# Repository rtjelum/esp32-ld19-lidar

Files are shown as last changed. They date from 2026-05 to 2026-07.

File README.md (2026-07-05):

# ESP32 LD19 LiDAR Project

This project implements a portable LiDAR scanner and visualization tool using a **LilyGo T-Display-S3** (ESP32-S3 with AMOLED display) and an **LD19 LiDAR** sensor.

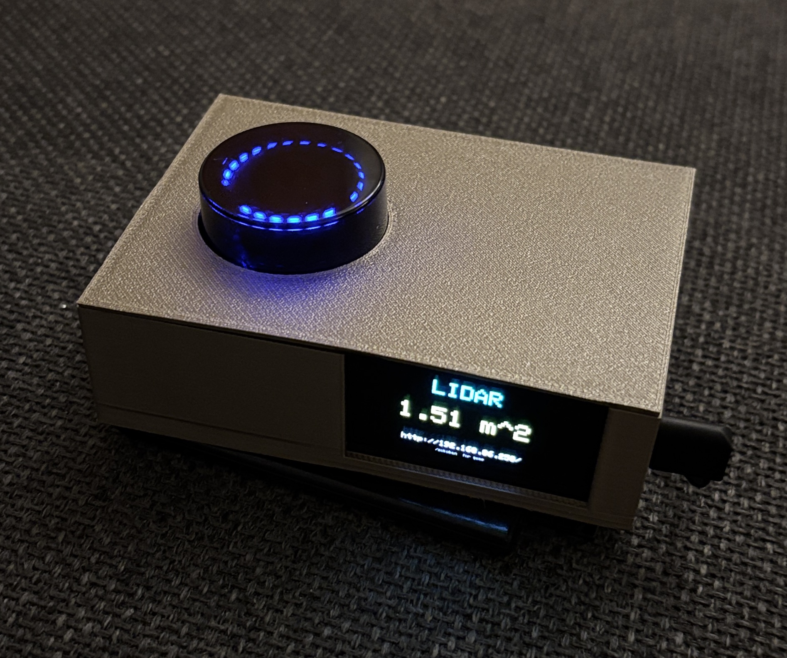
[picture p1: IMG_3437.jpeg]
Project Overview


*The assembled LiDAR scanner in its custom enclosure.*

## Features

- **Real-time Visualization:** Displays live LiDAR point cloud data on the 536x240 AMOLED screen.
- **Touch UI:** On-screen buttons (CST816 capacitive touch) to toggle person tracking, an area-only view, the IMU readout, and recording.
- **IMU:** Optional BMI160 (accel + gyro) for motion deskew; shown live on screen and logged with the LiDAR.
- **On-device Recording:** Logs synchronized LiDAR + IMU to the onboard flash as `.ldim`, downloadable over WiFi.
- **Host Toolchain:** Pull recordings and turn them into floorplans, MCAP, or an interactive 3-D view (`tools/`).
- **Web Interface:** Includes a built-in web server to monitor data and configure the device over WiFi.
- **Custom Enclosure:** A two-piece 3D-printable snap-fit box designed specifically for these components.
- **Integrated Game:** Includes a built-in Sokoban game (reachable via the display/buttons).
- **Closed-loop Speed Control:** Holds the LiDAR at a default 10 Hz for consistent data acquisition.

## Hardware

- **MCU:** [LilyGo T-Display-S3 AMOLED](https://www.lilygo.cc/products/t-display-s3) (ESP32-S3, RM67162 536×240 AMOLED)
- **LiDAR:** LD19 LiDAR Sensor — RX on GPIO 44, speed PWM on GPIO 46
- **Touch:** CST816 capacitive controller (on-board, I²C bus 0 — SDA 3 / SCL 2, addr 0x15)
- **IMU (optional):** BMI160 accel + gyro on a second I²C bus (SDA 41 / SCL 39, addr 0x69), mounted with **+Y up**
- **Enclosure:** Custom 3D-printed case (see `build_box.py`)

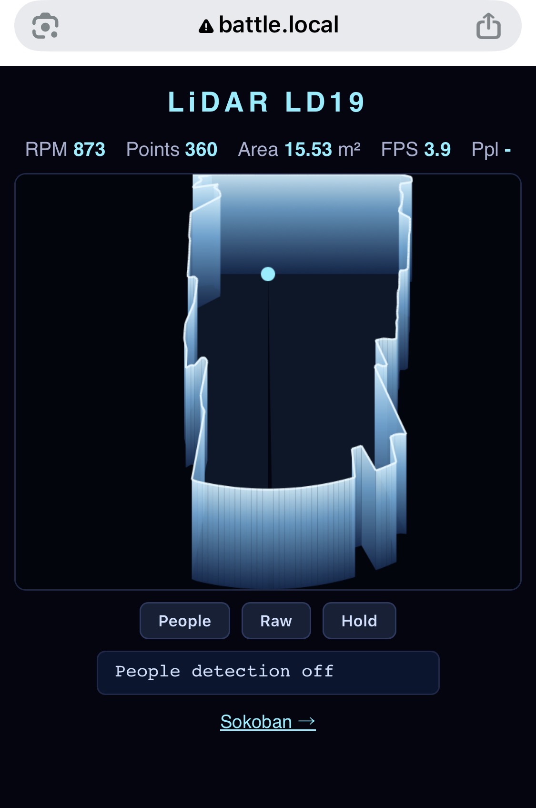
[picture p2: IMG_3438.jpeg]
Internal View


*Internal layout and component fitting.*

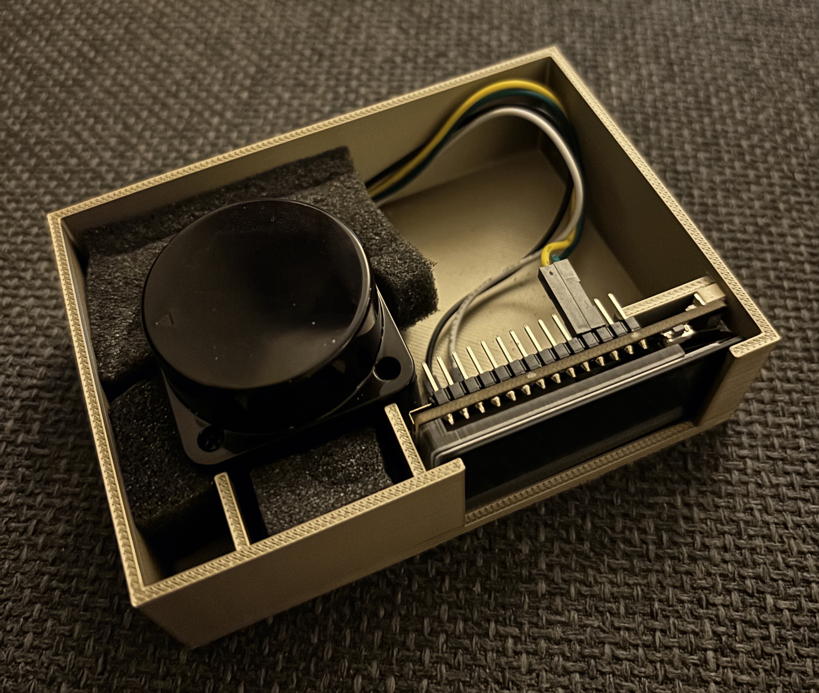
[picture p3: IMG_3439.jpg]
Component Placement


*LiDAR and T-Display seated in the bottom enclosure.*

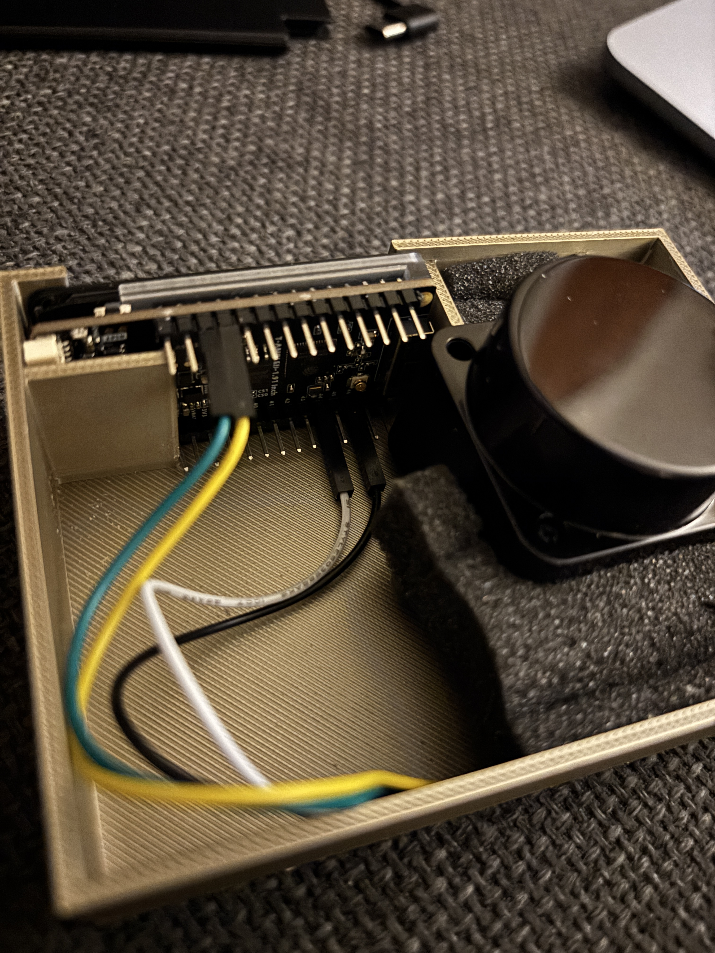
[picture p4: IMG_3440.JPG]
Wiring Detail


*Detail of the wiring connection between the MCU and the sensor.*

## Software Setup

### Firmware
The firmware is written in C++ for the Arduino framework. It uses the `Arduino_GFX` library for the AMOLED display.

**Build Requirements:**
- `arduino-cli`
- ESP32 Board Support (esp32:esp32:esp32s3)

To compile and flash:
```bash
make
```

### WiFi Setup

On first boot — or any boot with no stored credentials — the device starts a SoftAP captive setup:

1. Connect your phone or laptop to the WiFi network **`lidar-setup`** (open, no password).
2. Open **http://192.168.4.1/** in a browser. The setup page scans for nearby networks.
3. Tap an SSID to fill the field (or type it manually), enter the password, and press **Connect**.
4. The device stores the credentials in flash and reboots. The AMOLED then shows the station-mode URL (typically `http://lidar.local/` via mDNS).

To re-do setup later, open a serial console at 115200 baud and type one of:

- `clear` — wipes stored WiFi credentials and reboots into setup mode
- `reboot` — restart the device
- `help` — list commands

### Sokoban

The device serves a built-in Sokoban game at **http://lidar.local/sokoban** (or `/sokoban` on whichever IP is shown on the display).

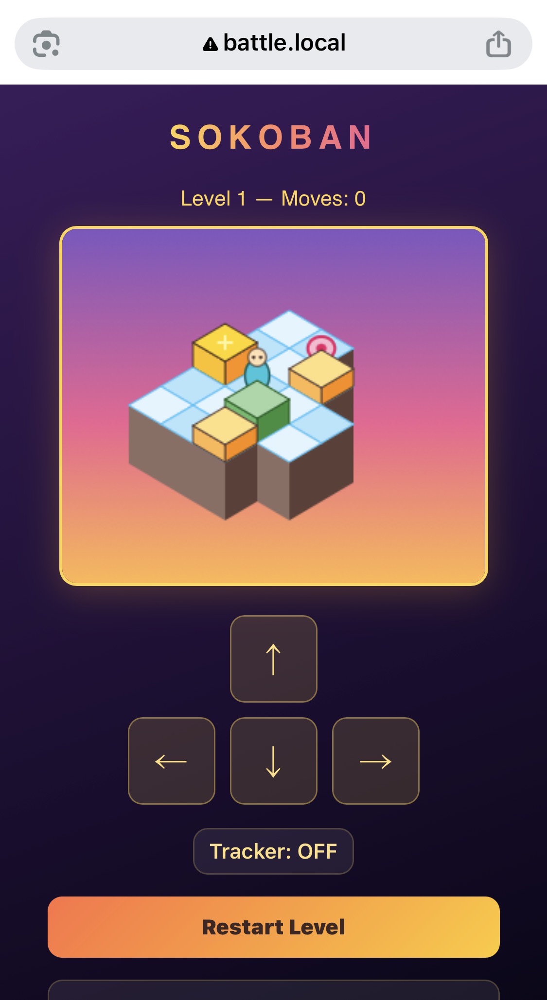
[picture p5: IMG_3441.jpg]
Sokoban running in a browser


*Sokoban running on the embedded web server, rendered isometrically.*

Push the green crates onto the pink goal pads. Each pad must hold one crate to clear the level — there are 50 levels in total, advancing automatically when the last crate is placed. Crates can only be pushed (never pulled) and only when the square behind them is empty, so plan ahead.

Two control modes:

- **D-pad / arrow keys** — tap the on-screen pad or use arrow keys on a desktop.
- **LiDAR motion control** — toggle **Tracker: ON** to stand in front of the sensor and step into one of the four direction cells in the 3×3 floor grid (the centre cell is "idle"). Each cell-entry fires one move; you have to step back to idle before re-entering the same cell.

### Touch Controls

The AMOLED's capacitive panel drives a four-button bar along the bottom of every screen:

- **TRACK** — toggle firmware person detection on/off (area measurement keeps running).
- **AREA** — full-screen scanned-area (m²) readout.
- **IMU** — live BMI160 readout (accel in g, gyro in dps, roll/pitch). Use it to align the mount: when upright the up axis reads ~+1.00 g and roll/pitch sit near 0.
- **REC** — start/stop recording. While recording the button turns red and shows the file size.

The LiDAR spins at a default **10 Hz** (closed-loop) from boot.

To sanity-check the touch panel in isolation, flash the standalone test sketch (it scans I²C and live-tracks touches), then re-flash the main firmware:

```bash
make touch-flash    # flash touch_test/
make flash          # restore the LiDAR firmware
```

### Recording & Floorplans

Recordings are written to the onboard FAT partition as `scan_NNN.ldim` (raw LD19 packets + mount-corrected IMU samples, the same format as the companion `rasp_pi_zero2_ld19_lidar` project). A host-side toolchain in `tools/` pulls them over WiFi and processes them.

```bash
make gui                      # desktop control panel wrapping every tool below
make pull-recordings          # download new .ldim from the device into recordings/
make list-recordings          # list what's on the device (no download)
make clear-device             # wipe all recordings on the device (skips the active one)
make clear-recordings         # delete local recordings + derived .mcap/.png
make floorplan                # deskew + point-to-line ICP + loop-closure floorplan PNG
make path                     # position-path PNG (SLAM trajectory over a faint map)
make viz                      # interactive PRBonn lidar-visualizer (auto-builds MCAP)
make mcap                     # just convert .ldim -> MCAP
make view                     # quick static matplotlib scatter
make dump                     # print a recording's duration + LD19/IMU counts
make help                     # list every make target
```

All processing targets default to the newest recording; override with `LDIM=recordings/scan_002.ldim`, and the device host with `HOST=lidar.local`. The Python venv (`tools/.venv`) is created automatically and **pins Python 3.13** (the visualizer / `rosbags` lack wheels for 3.14). `make viz` clones [PRBonn/lidar-visualizer](https://github.com/PRBonn/lidar-visualizer) on demand.

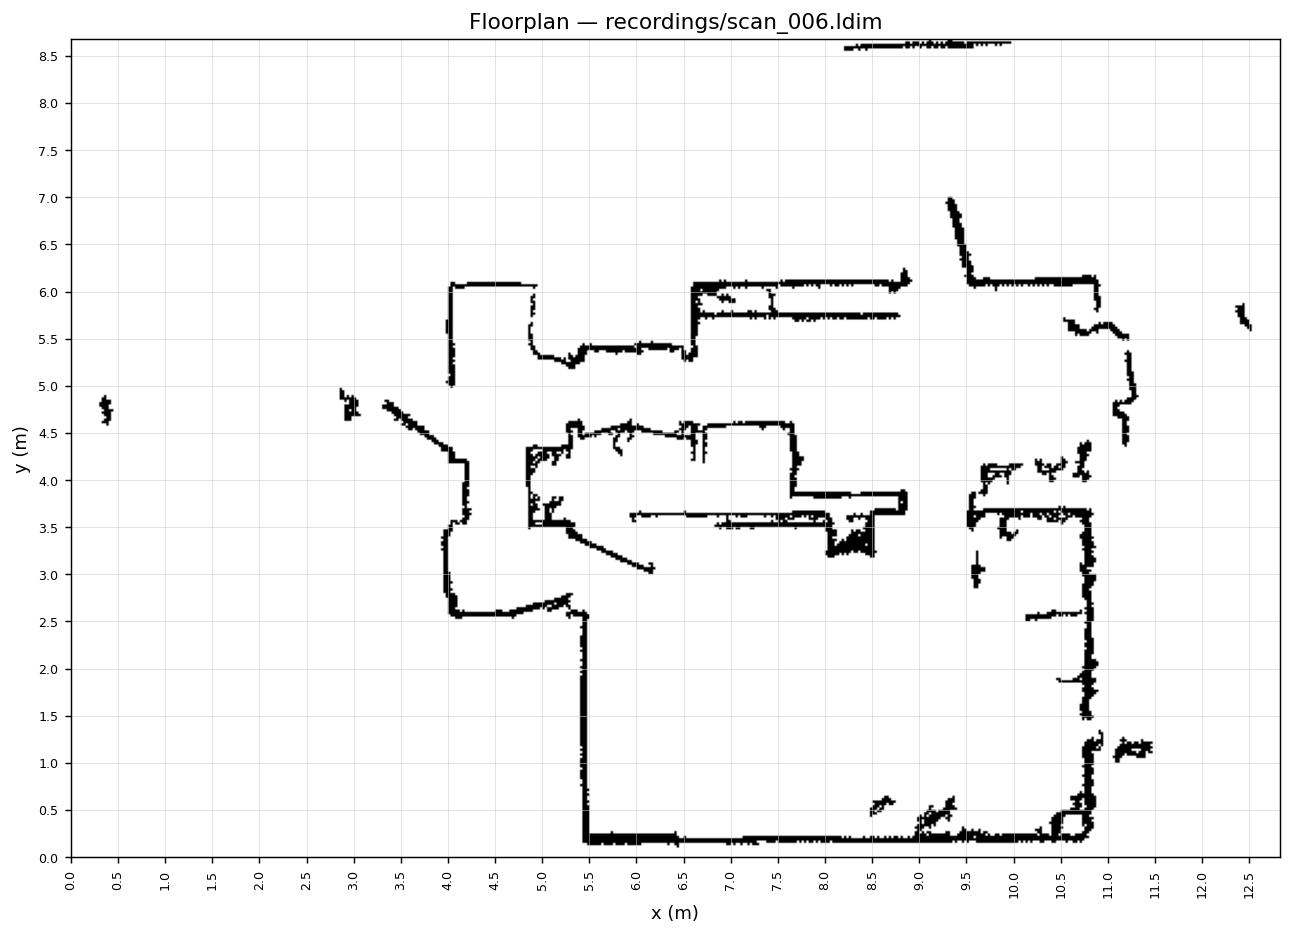
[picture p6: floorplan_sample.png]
Sample floorplan
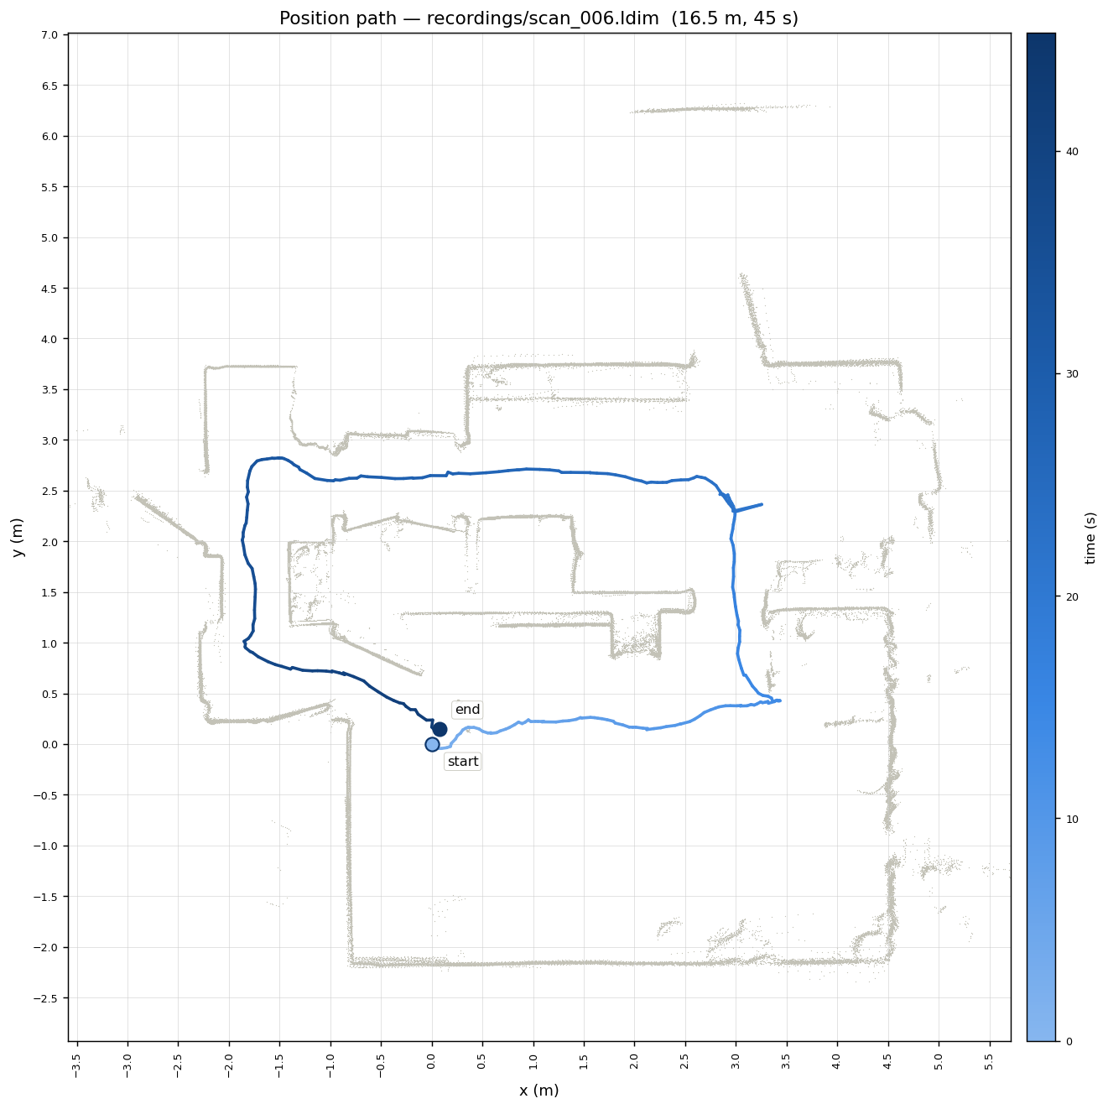
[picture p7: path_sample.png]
Sample position path
 

*From the same ~50 s handheld walk: the floorplan (`make floorplan` — gyro + translation deskew, point-to-line ICP, loop closure, global refinement) and the rig's position path over the same map (`make path` — light→dark blue with time).*

Recordings can also be managed over a 115200-baud serial console: `ls` (list), `rm <file>`, `i2c` (scan both buses for the touch/IMU controllers).

### Desktop GUI

```bash
make gui        # or: python3.13 lidar_gui.py
```

`lidar_gui.py` is a Tkinter control panel wrapping every make target above. It is stdlib-only but needs **Python 3.13** (the system `python3` ships without tkinter); the tools venv is built automatically the first time an action needs it.

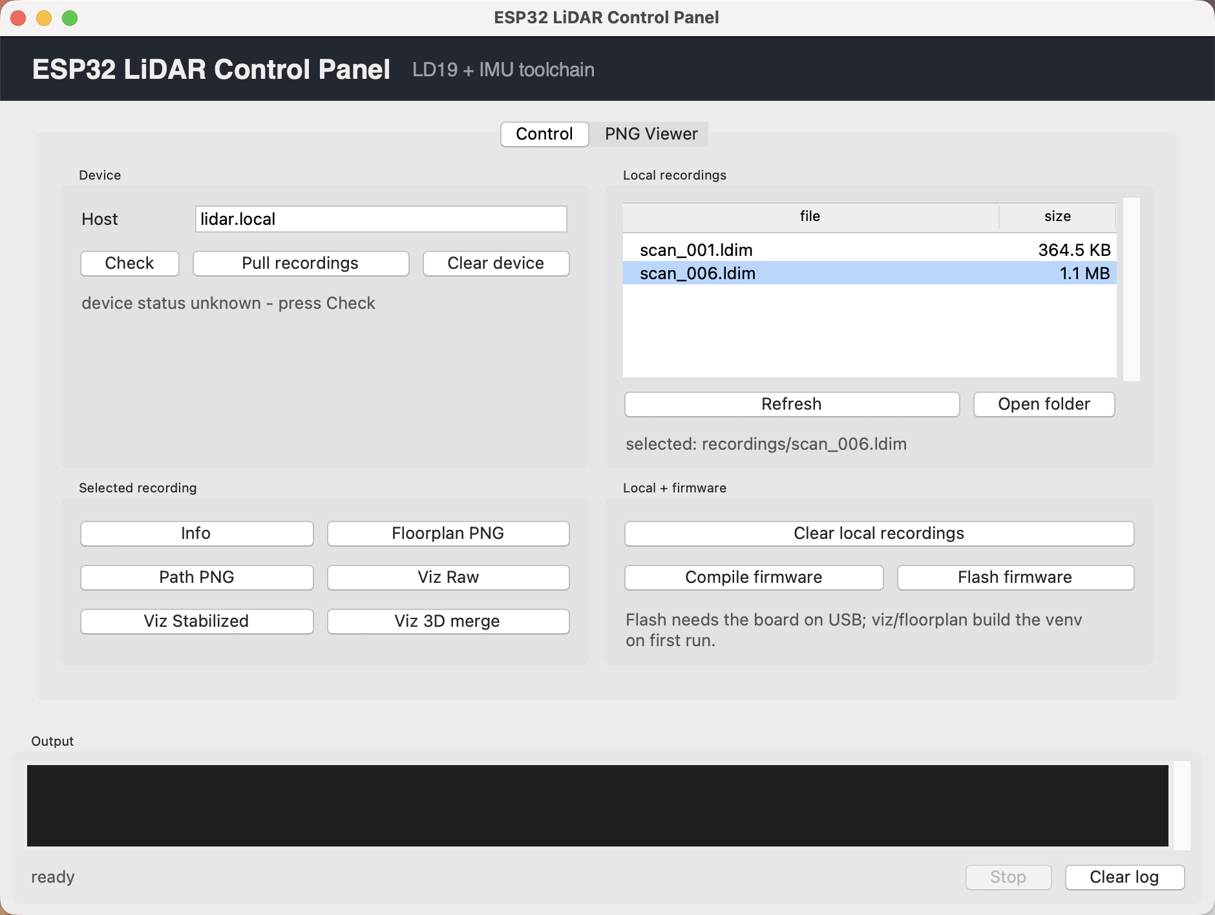
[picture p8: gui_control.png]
GUI Control tab


*The Control tab: device access, local recordings, per-recording actions, firmware, and the live output log.*

The window has two tabs plus a shared **Output** pane at the bottom that streams the live output of the running command — one command runs at a time, and **Stop** kills it.

**Control tab**

- **Device** — set the host (default `lidar.local`). **Check** shows the device's file count, free flash, and whether it is recording; **Pull recordings** downloads new `.ldim` files into `recordings/`; **Clear device** wipes the device (the file currently being recorded is skipped).
- **Local recordings** — lists `recordings/*.ldim` with the newest pre-selected; **Refresh** rescans, **Open folder** opens it in Finder.
- **Selected recording** — runs a tool on the highlighted file:
  - **Info** — duration + LD19/IMU sample counts (`make dump`)
  - **Floorplan PNG** — SLAM floorplan (`make floorplan`)
  - **Path PNG** — the rig's position path over a faint point map (`make path`)
  - **Viz Raw / Viz Stabilized / Viz 3D merge** — the interactive 3-D viewers (`make viz` / `viz3d` / `viz3d-merge`)
- **Local + firmware** — delete local recordings and their derived files, compile the firmware, or flash it over USB.

**PNG Viewer tab** — browses the PNGs under `recordings/`, scaled to fit the window; **Open externally** hands the file to Preview. The two PNG-producing buttons (Floorplan, Path) switch to this tab automatically when they finish.

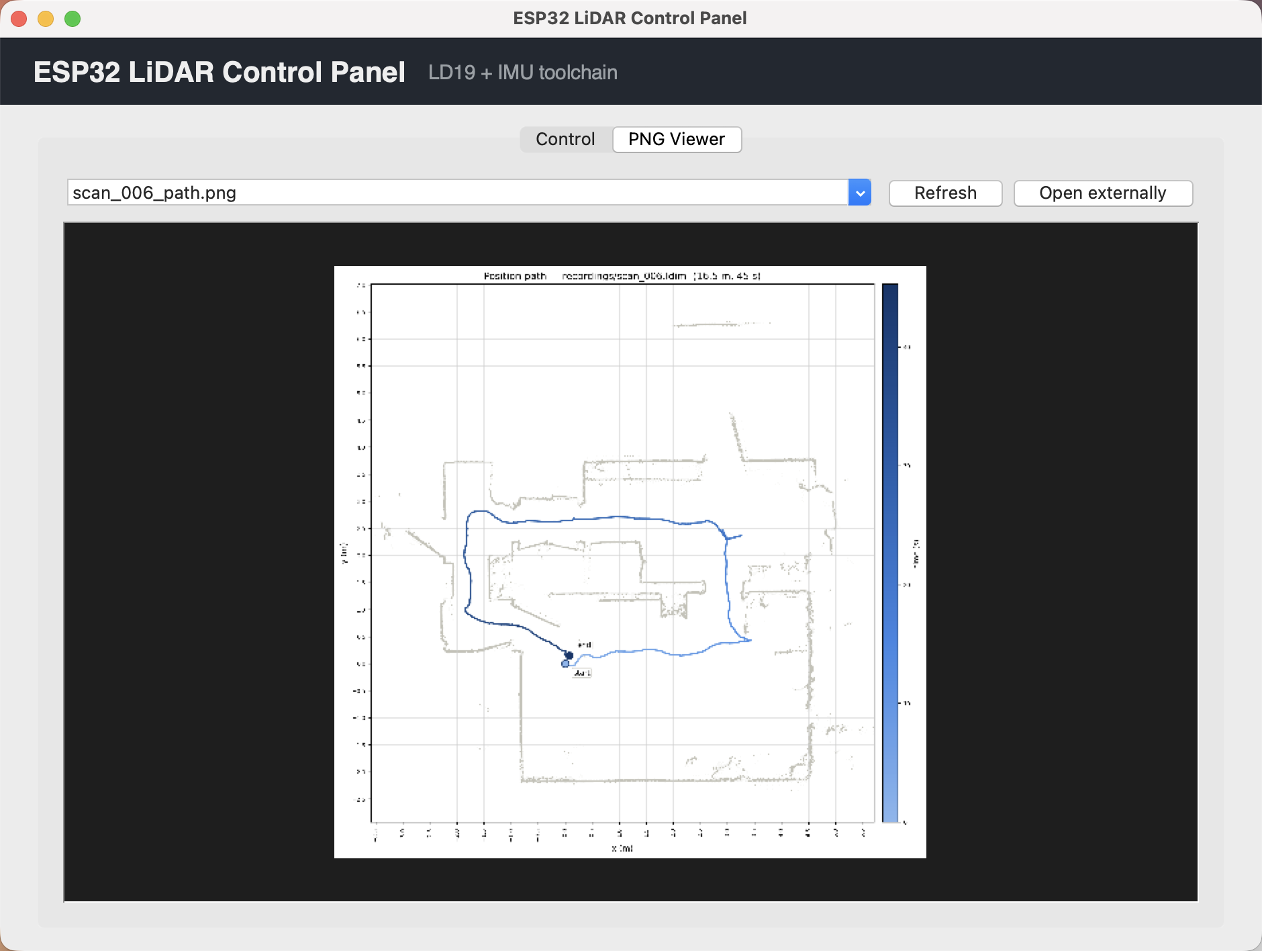
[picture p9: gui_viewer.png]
GUI PNG Viewer tab


*The PNG Viewer tab showing a position-path render.*

### Enclosure Design
The 3D-printable box is generated using a Python script that leverages geometric libraries.

**Requirements:**
- Python 3
- `numpy`
- `trimesh`
- `shapely`

To generate the STL files:
```bash
python3 build_box.py
```
This will produce `lidar_tdisplay_box_bottom.stl` and `lidar_tdisplay_box_top.stl`.

## File Structure

- `esp32-ld19-lidar.ino`: Main Arduino firmware.
- `lidar_page.h`, `sokoban_page.h`, `setup_page.h`, `sokoban_levels.h`, `localizer.h`: Web-page HTML, Sokoban data, and the localizer, included by the sketch.
- `touch_test/`: Standalone CST816 touch-panel test sketch (`make touch-flash`).
- `lidar_gui.py`: Tkinter desktop control panel for the host toolchain (`make gui`).
- `tools/`: Host `.ldim` toolchain — `pull_recordings.py`, `view_ldim.py`, `ldim_to_floorplan.py`, `ldim_to_mcap.py`, `ldim_to_3d_mcap.py`, `ldim_dump.py`.
- `build_box.py`: Python script to generate the 3D enclosure.
- `makefile`: Build system for the firmware and the host toolchain.
- `*.stl`: Generated 3D models for printing.
- `IMG_*.jpeg`: Project photos.

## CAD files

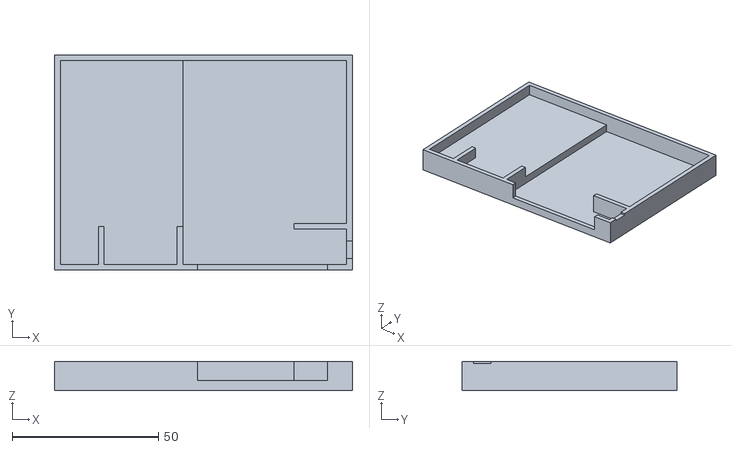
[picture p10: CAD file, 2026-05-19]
lidar_tdisplay_box_testfit.stl
102.0 x 73.7 x 10.0

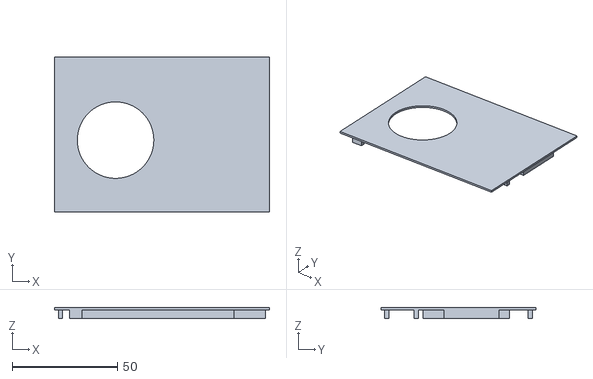
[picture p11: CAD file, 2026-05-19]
lidar_tdisplay_box_top.stl
102.0 x 73.7 x 5.00

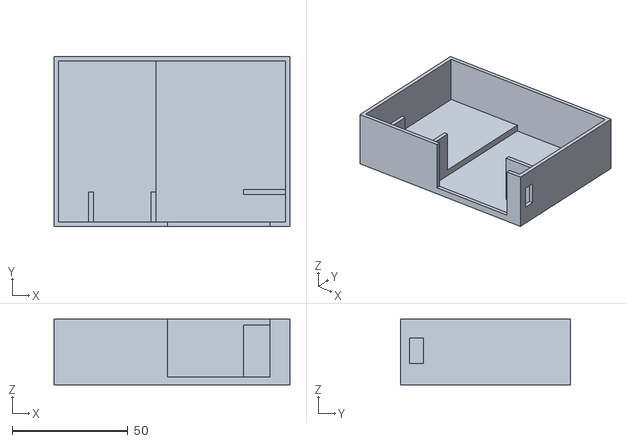
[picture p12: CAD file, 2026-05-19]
lidar_tdisplay_box_bottom.stl
102.0 x 73.7 x 28.5

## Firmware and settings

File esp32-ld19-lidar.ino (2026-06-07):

#include <WiFi.h>
#include <ESPmDNS.h>
#include <WebServer.h>
#include <Preferences.h>
#include <Arduino_GFX_Library.h>
#include <Wire.h>
#include <FFat.h>
#include <esp_timer.h>
#include "lidar_page.h"
#include "sokoban_page.h"
#include "sokoban_levels.h"
#include "setup_page.h"
#include "localizer.h"

// ── AMOLED (RM67162, 536×240 physical) ──────────────────────────────────────
#define LCD_CS   6
#define LCD_SCLK 47
#define LCD_D0   18
#define LCD_D1   7
#define LCD_D2   48
#define LCD_D3   5
#define LCD_RST  17
#define LCD_PWR  15

#define BLACK  0x0000
#define WHITE  0xFFFF
#define GREEN  0x0500
#define BLUE   0x0016

// ── Touch (CST816 capacitive, I2C) ──────────────────────────────────────────
#define TOUCH_SDA  3
#define TOUCH_SCL  2
#define TOUCH_INT  21
#define TOUCH_ADDR 0x15
struct TouchPt { bool pressed; uint16_t x, y; };

// ── IMU on a second I2C bus (Wire1) ─────────────────────────────────────────
#define IMU_SDA  41
#define IMU_SCL  39

Arduino_DataBus *bus = nullptr;
Arduino_GFX     *gfx_dev = nullptr;
Arduino_Canvas  *gfx = nullptr; // off-screen PSRAM framebuffer; flush() pushes to gfx_dev

static const int DISP_W = 536;
static const int DISP_H = 240;

Preferences prefs;
char ssid[64]     = "";
char password[64] = "";

constexpr uint32_t fnv1a(const char* s, uint32_t h = 2166136261u) {
    return *s ? fnv1a(s + 1, (h ^ (uint8_t)*s) * 16777619u) : h;
}
constexpr uint32_t BUILD_HASH = fnv1a(__DATE__ " " __TIME__);

static bool          apMode = false;
static unsigned long skLastSeen = 0;
WebServer server(80);

// ── LiDAR LD19 ────────────────────────────────────────────────────────────────
#define LIDAR_RX_PIN  44
#define LIDAR_PWM_PIN 46
#define LIDAR_PWM_FREQ 1000   // LD19P external speed control: 500 Hz – 1.5 kHz
#define LIDAR_PWM_RES  8
#define LIDAR_BAUD   230400
#define LIDAR_PKT_LEN 47
#define LIDAR_POINTS_PER_PKT 12
// Returns are clamped to the LD19's rated maximum range. The sensor does not
// report valid hits beyond this, so it acts as a safety ceiling rather than an
// artificial limit. Front and rear are treated symmetrically to avoid the
// rendering discontinuity at the 90°/270° boundary.
#define LIDAR_MAX_RANGE_MM 12000
static const int LIDAR_BUF_POINTS = 480; // ~40 packets, ≈ 1 full rotation @10Hz
static volatile uint8_t  lidarPwmDuty   = 128;   // 50% — also LD19 external-mode entry duty
static volatile bool     lidarMotorOn   = true;
static volatile uint32_t lidarPwmFreq   = LIDAR_PWM_FREQ;
static volatile bool     lidarPwmInvert = false;
static volatile uint16_t lidarTargetRpm = 600;   // default 10 Hz closed-loop (0 = manual duty)
static inline void applyLidarPwm(){
  uint32_t d = lidarMotorOn ? lidarPwmDuty : 0;
  if (lidarPwmInvert) d = 255 - d;
  ledcWrite(LIDAR_PWM_PIN, d);
}

struct LidarPt { uint16_t angle_q2; uint16_t dist; uint8_t intensity; };
static LidarPt lidarBuf[LIDAR_BUF_POINTS];
static volatile uint16_t lidarHead = 0;
static volatile uint32_t lidarSeq  = 0;
static volatile uint16_t lidarSpeed = 0; // deg/sec
static portMUX_TYPE lidarMux = portMUX_INITIALIZER_UNLOCKED;

// ── Person detection state (posted back from browser via /people) ────────────
static portMUX_TYPE personMux = portMUX_INITIALIZER_UNLOCKED;
static volatile uint32_t personLastSeen = 0;
static volatile uint8_t  personCount = 0;
static const uint8_t PERSON_MAX = 6;
static float personAngle[PERSON_MAX]; // degrees, 0°=left, 90°=front, 180°=right
static float personDist[PERSON_MAX];  // meters
static float personX[PERSON_MAX];     // meters, +right
static float personY[PERSON_MAX];     // meters, +forward
static float bgDist[360];    // mm, per-bin rolling background for shadow detection
static volatile float lidarAreaM2 = 0.0f; // scanned polygon area in m²

// ── Touch UI state ───────────────────────────────────────────────────────────
static volatile bool personTrackingOn = true;  // TRACK button: gate personTask detection
static volatile bool bigAreaView      = false; // AREA button: full-screen m² readout
static volatile bool displayDirty     = false; // set by touchTask to force an immediate repaint
static volatile int  btnPressedIdx    = -1;    // which button is held (for press highlight)

// ── Recording state (REC button) ──────────────────────────────────────────────
// Writes raw LD19 packets to a .ldim file on the onboard 9 MB FAT partition, in
// the same format as ../rasp_pi_zero2_ld19_lidar (tools/ldim_*.py can read them).
// recWant is toggled by the touch task; all file I/O happens in lidarTask, which
// owns recFile, so no cross-task file locking is needed.
static volatile bool     recWant   = false;  // desired state (set by touch)
static volatile bool     recActive = false;  // actual state (set by lidarTask)
static volatile uint32_t recBytes  = 0;      // bytes written so far
static volatile int      recNo     = 0;      // current scan_NNN number
static File              recFile;
static int64_t           recStartUs = 0;
static SemaphoreHandle_t recMutex   = nullptr; // serializes recFile across lidar/imu tasks

// ── BMI160 IMU on Wire1 (addr 0x69) ────────────────────────────────────────────
#define BMI160_ADDR     0x69
#define BMI160_CHIPID   0xD1
static volatile bool  imuOk = false;
static volatile bool  imuView = false;                 // IMU button: live readout view
static volatile float imuAx = 0, imuAy = 0, imuAz = 0; // g, EMA-smoothed
static volatile float imuGx = 0, imuGy = 0, imuGz = 0; // dps, EMA-smoothed

// ── Localization state ──────────────────────────────────────────────────────
static portMUX_TYPE poseMux = portMUX_INITIALIZER_UNLOCKED;
static volatile float locX = 0.0f, locY = 0.0f, locTheta = 0.0f;
static volatile float locErr = 0.0f;
static volatile int   locInliers = 0;
static volatile bool  locValid = false;     // true once first ICP converges
static volatile bool  seedResetRequested = false;  // /lidar/map/reset sets this

static const uint8_t LD19_CRC_TABLE[256] = {
  0x00,0x4d,0x9a,0xd7,0x79,0x34,0xe3,0xae,0xf2,0xbf,0x68,0x25,0x8b,0xc6,0x11,0x5c,
  0xa9,0xe4,0x33,0x7e,0xd0,0x9d,0x4a,0x07,0x5b,0x16,0xc1,0x8c,0x22,0x6f,0xb8,0xf5,
  0x1f,0x52,0x85,0xc8,0x66,0x2b,0xfc,0xb1,0xed,0xa0,0x77,0x3a,0x94,0xd9,0x0e,0x43,
  0xb6,0xfb,0x2c,0x61,0xcf,0x82,0x55,0x18,0x44,0x09,0xde,0x93,0x3d,0x70,0xa7,0xea,
  0x3e,0x73,0xa4,0xe9,0x47,0x0a,0xdd,0x90,0xcc,0x81,0x56,0x1b,0xb5,0xf8,0x2f,0x62,
  0x97,0xda,0x0d,0x40,0xee,0xa3,0x74,0x39,0x65,0x28,0xff,0xb2,0x1c,0x51,0x86,0xcb,
  0x21,0x6c,0xbb,0xf6,0x58,0x15,0xc2,0x8f,0xd3,0x9e,0x49,0x04,0xaa,0xe7,0x30,0x7d,
  0x88,0xc5,0x12,0x5f,0xf1,0xbc,0x6b,0x26,0x7a,0x37,0xe0,0xad,0x03,0x4e,0x99,0xd4,
  0x7c,0x31,0xe6,0xab,0x05,0x48,0x9f,0xd2,0x8e,0xc3,0x14,0x59,0xf7,0xba,0x6d,0x20,
  0xd5,0x98,0x4f,0x02,0xac,0xe1,0x36,0x7b,0x27,0x6a,0xbd,0xf0,0x5e,0x13,0xc4,0x89,
  0x63,0x2e,0xf9,0xb4,0x1a,0x57,0x80,0xcd,0x91,0xdc,0x0b,0x46,0xe8,0xa5,0x72,0x3f,
  0xca,0x87,0x50,0x1d,0xb3,0xfe,0x29,0x64,0x38,0x75,0xa2,0xef,0x41,0x0c,0xdb,0x96,
  0x42,0x0f,0xd8,0x95,0x3b,0x76,0xa1,0xec,0xb0,0xfd,0x2a,0x67,0xc9,0x84,0x53,0x1e,
  0xeb,0xa6,0x71,0x3c,0x92,0xdf,0x08,0x45,0x19,0x54,0x83,0xce,0x60,0x2d,0xfa,0xb7,
  0x5d,0x10,0xc7,0x8a,0x24,0x69,0xbe,0xf3,0xaf,0xe2,0x35,0x78,0xd6,0x9b,0x4c,0x01,
  0xf4,0xb9,0x6e,0x23,0x8d,0xc0,0x17,0x5a,0x06,0x4b,0x9c,0xd1,0x7f,0x32,0xe5,0xa8
};

static uint8_t ld19Crc(const uint8_t* p, int n) {
  uint8_t c = 0;
  for (int i = 0; i < n; i++) c = LD19_CRC_TABLE[(c ^ p[i]) & 0xff];
  return c;
}

// ── Touch panel (CST816) + on-screen buttons ───────────────────────────────────
static bool touchRead(uint8_t reg, uint8_t *buf, uint8_t len) {
  Wire.beginTransmission(TOUCH_ADDR);
  Wire.write(reg);
  if (Wire.endTransmission(false) != 0) return false;
  if (Wire.requestFrom((int)TOUCH_ADDR, (int)len) != len) return false;
  for (uint8_t i = 0; i < len; i++) buf[i] = Wire.read();
  return true;
}

// One CST816 report: gesture, finger count, then X/Y hi/lo. The panel reports
// already in the landscape (536×240) frame, so x/y map straight to the canvas.
static TouchPt touchPoll() {
  TouchPt t = {false, 0, 0};
  uint8_t d[6];
  if (!touchRead(0x01, d, 6)) return t;
  uint8_t fingers = d[1];
  if (fingers == 0 || fingers > 2) return t;
  t.pressed = true;
  t.x = ((uint16_t)(d[2] & 0x0F) << 8) | d[3];
  t.y = ((uint16_t)(d[4] & 0x0F) << 8) | d[5];
  return t;
}

// Bottom button bar: four buttons across the 536-wide screen.
static const int BTN_N = 4;
static const int BTN_Y = 186, BTN_H = 48, BTN_W = 124;
static const int BTN_X[BTN_N] = {8, 140, 272, 404};

static int hitTestButton(int sx, int sy) {
  if (sy < BTN_Y || sy > BTN_Y + BTN_H) return -1;
  for (int i = 0; i < BTN_N; i++)
    if (sx >= BTN_X[i] && sx < BTN_X[i] + BTN_W) return i;
  return -1;
}

static void drawButton(int i, const char* label, bool active, uint16_t accent) {
  bool pressed = (btnPressedIdx == i);
  uint16_t fill = pressed ? 0x39C7 : (active ? ((accent >> 1) & 0x7BEF) : BLACK);
  uint16_t edge = active ? accent : 0x4a69;
  uint16_t txt  = active ? accent : WHITE;
  gfx->fillRoundRect(BTN_X[i], BTN_Y, BTN_W, BTN_H, 8, fill);
  gfx->drawRoundRect(BTN_X[i], BTN_Y, BTN_W, BTN_H, 8, edge);
  gfx->setTextSize(2);
  gfx->setTextColor(txt);
  int tw = (int)strlen(label) * 12;
  gfx->setCursor(BTN_X[i] + (BTN_W - tw) / 2, BTN_Y + (BTN_H - 16) / 2);
  gfx->print(label);
}

static void drawTouchButtons() {
  drawButton(0, personTrackingOn ? "TRACK ON" : "TRACK OFF", personTrackingOn, 0x07E0);
  drawButton(1, "AREA", bigAreaView, 0x07E0);
  drawButton(2, "IMU", imuView, 0x07E0);
  char rl[12];
  if (recActive) snprintf(rl, sizeof(rl), "REC %.1fM", recBytes / 1048576.0);
  else           strcpy(rl, "REC");
  drawButton(3, rl, recActive, 0xF800);  // red accent
}

// ── Recording (.ldim) — only ever called from lidarTask ────────────────────────
static int recNextNumber() {
  int mx = 0;
  File root = FFat.open("/");
  if (root) {
    for (File f = root.openNextFile(); f; f = root.openNextFile()) {
      const char* nm = f.name();
      const char* slash = strrchr(nm, '/');
      if (slash) nm = slash + 1;
      int n;
      if (sscanf(nm, "scan_%d.ldim", &n) == 1 && n > mx) mx = n;
      f.close();
    }
    root.close();
  }
  return mx + 1;
}

// Append a record (12-byte header + payload). Caller must hold recMutex.
// Append a record with an explicit monotonic timestamp (ns since recStartUs).
// Used by the IMU path to back-date FIFO frames to their true acquisition time
// instead of the (bunched) drain time.
static void recAppendAt(uint8_t type, const uint8_t* payload, uint16_t len, uint64_t ns) {
  if (!recActive || !recFile) return;
  uint8_t rh[12];
  memcpy(rh + 0, &ns, 8);
  rh[8] = type;
  rh[9] = 0;
  memcpy(rh + 10, &len, 2);
  recFile.write(rh, 12);
  recFile.write(payload, len);
  recBytes += 12 + len;
}

static void recAppend(uint8_t type, const uint8_t* payload, uint16_t len) {
  recAppendAt(type, payload, len, (uint64_t)(esp_timer_get_time() - recStartUs) * 1000ull);
}

static void recStart() {
  recNo = recNextNumber();
  char path[32];
  snprintf(path, sizeof(path), "/scan_%03d.ldim", recNo);
  xSemaphoreTake(recMutex, portMAX_DELAY);
  recFile = FFat.open(path, "w");
  if (!recFile) {
    xSemaphoreGive(recMutex);
    Serial.printf("[rec] open %s failed\n", path);
    recWant = false; recActive = false;
    return;
  }
  uint8_t hdr[16] = {0};
  uint32_t magic = 0x4D49444C; // "LDIM"
  uint16_t ver   = 1;
  uint64_t startns = 0;        // no wallclock (no RTC/NTP)
  memcpy(hdr + 0, &magic, 4);
  memcpy(hdr + 4, &ver,   2);
  memcpy(hdr + 8, &startns, 8);
  recFile.write(hdr, 16);
  recBytes   = 16;
  recStartUs = esp_timer_get_time();
  recActive  = true;
  xSemaphoreGive(recMutex);
  Serial.printf("[rec] start %s%s\n", path, imuOk ? " (LD19+IMU)" : " (LD19 only)");
}

static void recStop() {
  xSemaphoreTake(recMutex, portMAX_DELAY);
  recActive = false;
  if (recFile) { recFile.flush(); recFile.close(); }
  xSemaphoreGive(recMutex);
  Serial.printf("[rec] stop scan_%03d.ldim (%u bytes)\n", recNo, (unsigned)recBytes);
}

// Delete every recording on the FAT partition except the one being recorded.
// Returns the number of files removed. Re-scans from the root each pass so we
// never remove a file out from under an open directory iterator.
static int recRemoveAll() {
  char curPath[32] = "";
  if (recActive) snprintf(curPath, sizeof(curPath), "/scan_%03d.ldim", recNo);
  int removed = 0;
  for (;;) {
    String victim;
    File root = FFat.open("/");
    for (File f = root.openNextFile(); f; f = root.openNextFile()) {
      String p = f.name();
      if (!p.startsWith("/")) p = "/" + p;
      f.close();
      if (p != curPath) { victim = p; break; }
    }
    root.close();
    if (victim.length() == 0) break;
    if (!FFat.remove(victim)) break;   // stop rather than spin if a remove fails
    removed++;
  }
  return removed;
}

// Append one raw LD19 packet (47 bytes), type 0. Called from lidarTask.
static void recWritePacket(const uint8_t* pkt) {
  if (!recActive) return;
  xSemaphoreTake(recMutex, portMAX_DELAY);
  recAppend(0, pkt, LIDAR_PKT_LEN);
  xSemaphoreGive(recMutex);
}

// Append one BMI160 sample (12 bytes: GYR XYZ then ACC XYZ, mount-corrected
// int16 LE), type 1, at acquisition time ns. Called from imuTask. Matches the
// .ldim IMU payload spec.
static void recWriteImu(const uint8_t* d12, uint64_t ns) {
  if (!recActive) return;
  xSemaphoreTake(recMutex, portMAX_DELAY);
  recAppendAt(1, d12, 12, ns);
  xSemaphoreGive(recMutex);
}

// ── BMI160 IMU driver (Wire1) ──────────────────────────────────────────────────
static bool imuWrite(uint8_t reg, uint8_t val) {
  Wire1.beginTransmission(BMI160_ADDR);
  Wire1.write(reg); Wire1.write(val);
  return Wire1.endTransmission() == 0;
}

static bool imuReadReg(uint8_t reg, uint8_t* buf, uint8_t len) {
  Wire1.beginTransmission(BMI160_ADDR);
  Wire1.write(reg);
  if (Wire1.endTransmission(false) != 0) return false;
  if (Wire1.requestFrom((int)BMI160_ADDR, (int)len) != (int)len) return false;
  for (uint8_t i = 0; i < len; i++) buf[i] = Wire1.read();
  return true;
}

static bool imuInit() {
  uint8_t id = 0;
  if (!imuReadReg(0x00, &id, 1) || id != BMI160_CHIPID) {
    Serial.printf("[imu] chip id 0x%02X (expected 0x%02X)\n", id, BMI160_CHIPID);
    return false;
  }
  imuWrite(0x7E, 0x11); delay(5);    // CMD: accel normal power mode
  imuWrite(0x7E, 0x15); delay(80);   // CMD: gyro normal power mode
  imuWrite(0x41, 0x03);              // ACC_RANGE ±2g  -> 16384 LSB/g
  imuWrite(0x43, 0x00);              // GYR_RANGE ±2000 dps -> 16.4 LSB/dps
  imuWrite(0x40, 0x2A);              // ACC_CONF: ODR 400 Hz, normal filter
  imuWrite(0x42, 0x2A);              // GYR_CONF: ODR 400 Hz, normal filter

  // FIFO: headerless, gyro + accel. With both axes enabled at the *same* ODR,
  // each frame is a fixed 12 bytes (GYR XYZ then ACC XYZ, LE) — identical to the
  // 0x0C burst the old polled path read, so frame parsing below reuses the same
  // mount transform. imuTask drains the 1 KB FIFO in bursts, so the sample rate
  // is set by the sensor ODR (400 Hz), not the task wake period.
  imuWrite(0x47, 0xC0);              // FIFO_CONFIG_1: fifo_gyr_en + fifo_acc_en, headerless
  imuWrite(0x7E, 0xB0); delay(2);    // CMD: fifo_flush (drop any partial/legacy frames)
  Serial.println("[imu] BMI160 ready @ 0x69 on Wire1 (accel + gyro, FIFO 400 Hz)");
  return true;
}

// ── Display ───────────────────────────────────────────────────────────────────
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
void loop() {
  if (Serial.available()) {
    String cmd = Serial.readStringUntil('\n');
    cmd.trim();
    if (cmd == "clear") {
      Serial.println("[cmd] Clearing WiFi settings...");
      prefs.begin("wifi", false);
      prefs.clear();
      prefs.end();
      WiFi.disconnect(true, true);
      Serial.println("[cmd] Done. Restarting...");
      delay(500);
      ESP.restart();
    } else if (cmd == "reboot") {
      Serial.println("[cmd] Restarting...");
      delay(500);
      ESP.restart();
    } else if (cmd == "ls") {
      File root = FFat.open("/");
      uint32_t total = 0; int count = 0;
      for (File f = root.openNextFile(); f; f = root.openNextFile()) {
        Serial.printf("  %-20s %8u bytes\n", f.name(), (unsigned)f.size());
        total += f.size(); count++;
        f.close();
      }
      root.close();
      Serial.printf("[ls] %d file(s), %u bytes used, %u free\n",
                    count, (unsigned)total, (unsigned)FFat.freeBytes());
    } else if (cmd.startsWith("rm ")) {
      String fn = cmd.substring(3); fn.trim();
      if (!fn.startsWith("/")) fn = "/" + fn;
      Serial.println(FFat.remove(fn) ? "[rm] ok" : "[rm] failed");
    } else if (cmd == "rmall") {
      int n = recRemoveAll();
      Serial.printf("[rmall] deleted %d file(s)\n", n);
    } else if (cmd == "i2c") {
      Serial.println("[i2c] scanning bus (SDA=3 SCL=2)...");
      int found = 0;
      for (uint8_t addr = 1; addr < 0x7F; addr++) {
        Wire.beginTransmission(addr);
        if (Wire.endTransmission() == 0) {
          const char* note = "";
          if (addr == 0x15) note = " (CST816 touch)";
          else if (addr == 0x68 || addr == 0x69) note = " (IMU? MPU/BMI160/QMI8658)";
          else if (addr == 0x6A || addr == 0x6B) note = " (IMU? LSM6/BMI270)";
          else if (addr == 0x18 || addr == 0x19) note = " (accel?)";
          Serial.printf("  0x%02X%s\n", addr, note);
          found++;
        }
      }
      Serial.printf("[i2c] %d device(s) found\n", found);
      Serial.println("[i2c1] scanning IMU bus (SDA=41 SCL=39)...");
      int f1 = 0;
      for (uint8_t addr = 1; addr < 0x7F; addr++) {
        Wire1.beginTransmission(addr);
        if (Wire1.endTransmission() == 0) {
          Serial.printf("  0x%02X  whoami:", addr);
          // Dump candidate WHO_AM_I registers so we can identify the chip.
          for (uint8_t reg : {0x00, 0x0F, 0x75}) {
            Wire1.beginTransmission(addr);
            Wire1.write(reg);
            if (Wire1.endTransmission(false) == 0 && Wire1.requestFrom((int)addr, 1) == 1)
              Serial.printf(" [0x%02X]=0x%02X", reg, Wire1.read());
          }
          Serial.println();
          f1++;
        }
      }
      Serial.printf("[i2c1] %d device(s) found\n", f1);
    } else if (cmd == "help") {
      Serial.println("Available commands:");
      Serial.println("  clear  - Wipe WiFi credentials and reboot to AP mode");
      Serial.println("  reboot - Restart the ESP32");
      Serial.println("  ls     - List recordings on the FAT partition");
      Serial.println("  rm F   - Delete recording F (e.g. rm scan_001.ldim)");
      Serial.println("  rmall  - Delete all recordings (skips the active one)");
      Serial.println("  i2c    - Scan the I2C bus (touch / IMU detection)");
    }
  }
  delay(100);
}

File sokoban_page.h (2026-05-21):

#pragma once

// Sokoban game web page. Served at http://<device>/sokoban.
// Isometric canvas renderer with 50 built-in levels (defined inline in the JS
// `L` array — separate from sokoban_levels.h, which is currently unused).
// Two input modes: on-screen D-pad / arrow keys, and LiDAR motion control —
// the page polls /lidar/scan, maps the nearest detected person onto a 3x3
// floor grid in front of the sensor, and fires a move when they step into a
// new cell. The grid bounds (GRID_HX, GRID_Y0..Y1) are tunable in the JS.

static const char SOKOBAN_PAGE_HTML[] = R"rawhtml(<!DOCTYPE html><html><head><meta charset='utf-8'><meta name='viewport' content='width=device-width,initial-scale=1'><title>Sokoban</title><style>
*{box-sizing:border-box;margin:0;padding:0}
body{font-family:'Segoe UI',sans-serif;background:linear-gradient(160deg,#3a1c5a 0%,#1a0d2e 60%,#050510 100%);color:#fff3e0;min-height:100vh;padding:14px;display:flex;flex-direction:column;align-items:center;gap:10px}
h1{font-size:1.4rem;letter-spacing:4px;background:linear-gradient(90deg,#ffd54f,#ff8a65,#f06292);-webkit-background-clip:text;background-clip:text;color:transparent;margin:8px 0;font-weight:800}
#st{font-size:.9rem;color:#ffd54f;text-align:center}
canvas{background:#1b0d2e;border:2px solid #ffd54f;border-radius:12px;box-shadow:0 4px 24px rgba(255,167,38,.25);max-width:100%;height:auto;touch-action:none}
.btn{width:100%;max-width:310px;padding:12px;background:linear-gradient(135deg,#ff7043,#ffca28);border:none;border-radius:10px;color:#3e2723;font-size:.9rem;font-weight:800;cursor:pointer;margin-top:5px}
.btn.s{background:rgba(255,255,255,.08);color:#ffe082;font-weight:500;border:1px solid rgba(255,213,79,.2)}
.pad{display:grid;grid-template-columns:repeat(3,60px);gap:10px;margin-top:10px}
.pb{width:60px;height:60px;background:rgba(255,213,79,.15);border:1px solid rgba(255,213,79,.4);border-radius:10px;color:#ffe082;display:flex;align-items:center;justify-content:center;font-size:24px;user-select:none;-webkit-tap-highlight-color:transparent}
.pb:active{background:rgba(255,167,38,.5);color:#fff}
@media (hover:hover) and (pointer:fine){.pad,#btnRst,#btnReset{display:none!important}}
body.trk-on .pad{display:none!important}
body:not(.trk-on) #trkGrid,body:not(.trk-on) #trkStatus{display:none}
#trkBar{display:flex;flex-direction:column;align-items:center;gap:4px;margin-top:6px}
#trkStatus{font-size:.8rem;color:#cfe1ff;font-family:monospace}
#trkGrid{display:grid;grid-template-columns:repeat(3,70px);grid-template-rows:repeat(3,70px);gap:6px;position:relative}
.tc{width:70px;height:70px;background:rgba(255,213,79,.08);border:1px solid rgba(255,213,79,.2);border-radius:8px;display:flex;align-items:center;justify-content:center;font-size:30px;color:#ffe082}
.tc.b{visibility:hidden}
.tc.active{background:rgba(255,213,79,.78);color:#3e2723;border-color:#ffd54f}
#trkDot{position:absolute;width:18px;height:18px;border-radius:50%;background:#7cf0ff;border:2px solid #fff;box-shadow:0 0 10px #7cf0ff;pointer-events:none;display:none;transform:translate(-50%,-50%);z-index:2}
</style></head><body class='trk-on'>
<h1>SOKOBAN</h1><div id='st'>Moves: 0</div><canvas id='g' width='320' height='240'></canvas>
<div class='pad'>
<div></div><div class='pb' onclick='mvK(0,-1)'>&uarr;</div><div></div>
<div class='pb' onclick='mvK(-1,0)'>&larr;</div><div class='pb' onclick='mvK(0,1)'>&darr;</div><div class='pb' onclick='mvK(1,0)'>&rarr;</div>
</div>
<div id='trkBar'>
  <button class='btn s' id='trkBtn' style='max-width:220px;padding:6px 10px;margin-top:0' onclick='trkToggle()'>Tracker: ON</button>
  <div id='trkGrid'>
    <div class='tc b'></div><div class='tc' data-cell='up'>&uarr;</div><div class='tc b'></div>
    <div class='tc' data-cell='left'>&larr;</div><div class='tc' data-cell='idle'>&middot;</div><div class='tc' data-cell='right'>&rarr;</div>
    <div class='tc b'></div><div class='tc' data-cell='down'>&darr;</div><div class='tc b'></div>
    <div id='trkDot'></div>
  </div>
  <div id='trkStatus'>none</div>
</div>
<button class='btn' id='btnRst' onclick='reset()'>Restart Level</button>
<button class='btn s' onclick='location.href="/"'>Back to Menu</button>
<script>
var L=[["####","# .#","#  ###","#*@  #","#  $ #","#  ###","####"],
["######","#    #","# #@ #","# $* #","# .* #","#    #","######"],
["  ####","###  ####","#     $ #","# #  #$ #","# . .#@ #","#########"],
["########","#      #","# .**$@#","#      #","#####  #","    ####"],
[" #######"," #     #"," # .$. #","## $@$ #"," #  .$. #","#      #","########"],
["###### #####","#    ###   #","# $$     #@#","# $ #...   #","#   ########","#####"],
["#######","#     #","# .$. #","# $.$ #","# .$. #","# $.$ #","#  @  #","#######"],
["  ######","  # ..@#","  # $$ #","  ## ###","   # #","   # #","#### #","#    ##","# #   #","#   # #","###   #","  #####"],
["#####","#.  ##","#@$$ #","##   #"," ##  #","  ##.#","   ###"],
["      #####","      #.  #","      #.# #","#######.# #","# @ $ $ $ #","# # # # ###","#       #","#########"],
["  ######","  #    #","  # ##@##","### # $ #","# ..# $ #","#       #","#  ######","####"],
["#####","#   ##","# $  #","## $ ####"," ###@.  #","  #  .# #","  #     #","  #######"],
["####","#. ##","#.@ #","#. $#","##$ ###"," # $  #"," #    #"," #  ###"," ####"],
["#######","#     #","# # # #","#. $*@#","#   ###","#####"],
["     ###","######@##","#    .* #","#   #   #","#####$# #","    #   #","    #####"],
[" ####"," #  ####"," #     ##","## ##   #","#. .# @$##","#   # $$ #","#  .#    #","##########"],
["#####","# @ #","#...#","#$$$##","#    #","#    #","######"],
["#######","#     #","#. .  #","# ## ##","#  $ #","###$ #","  #@ #","  #  #","  ####"],
["########","#   .. #","#  @$$ #","##### ##","   #  #","   #  #","   #  #","   ####"],
["#######","#     ###","#  @$$..#","#### ## #","  #     #","  #  ####","  #  #","  ####"],
["####","#  ####","# . . #","# $$#@#","##    #"," ######"],
["#####","#   ###","#. .  #","#   # #","## #  #"," #@$$ #"," #    #"," #  ###"," ####"],
["#######","#  *  #","#     #","## # ##"," #$@.#"," #   #"," #####"],
["# #####","  #   #","###$$@#","#   ###","#     #","# . . #","#######"],
[" ####"," #  ###"," # $$ #","##... #","#  @$ #","#   ###","#####"],
[" #####"," # @ #"," #   #","###$ #","# ...#","# $$ #","###  #","  ####"],
["######","#   .#","# ## ##","#  $$@#","# #   #","#.  ###","#####"],
["#####","#   #","# @ #","# $$###","##. . #"," #    #"," ######"],
["     #####","     #   ##","     #    #"," ######   #","##     #. #","# $ $ @  ##","# ######.#","#        #","##########"],
["####","#  ###","# $$ #","#... #","# @$ #","#   ##","#####"],
["  ####"," ##  #","##@$.##","# $$  #","# . . #","###   #","  #####"],
[" ####","##  ###","#     #","#.**$@#","#   ###","##  #"," ####"],
["#######","#. #  #","#  $  #","#. $#@#","#  $  #","#. #  #","#######"],
["  ####","###  ####","#       #","#@$***. #","#       #","#########"],
["  ####"," ##  #"," #. $#"," #.$ #"," #.$ #"," #.$ #"," #. $##"," #   @#"," ##   #","  #####"],
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

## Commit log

2026-06-01 firmware: touch UI, 10 Hz default, BMI160 IMU, recording + download
    Add a CST816 capacitive-touch UI and IMU/recording pipeline to the LiDAR
    firmware:
    - Touch driver (Wire0, addr 0x15) + a 4-button bottom bar: TRACK (gate
    person detection), AREA (full-screen m^2 view), IMU (live readout),
    REC (start/stop recording). Debounced press edge; repaint on demand.
    - Default the LD19 to closed-loop 10 Hz at boot (removes the old "10 Hz"
    button; fixes the "WAITING LD19" state from an undriven motor).
    - BMI160 IMU on a second bus (Wire1, SCL=39/SDA=41, addr 0x69). Mounted
    +Y up; firmware rotates to a +Z-up body frame for the readout and
    records mount-corrected int16 so gyro Z is the yaw axis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
    [esp32-ld19-lidar.ino]
2026-06-01 tooling: CST816 touch test sketch + .ldim host toolchain
    - touch_test/: standalone sketch that scans I2C and live-tracks touches,
    with makefile touch-compile / touch-flash targets.
    - tools/: pull recordings over WiFi and process them, copied/adapted from
    ../rasp_pi_zero2_ld19_lidar:
    pull_recordings.py stdlib HTTP pull of /rec -> recordings/
    view_ldim.py quick matplotlib scatter
    ldim_to_floorplan.py deskew + ICP + loop-closure floorplan PNG
    ldim_to_mcap.py .ldim -> MCAP (LaserScan/PointCloud2/Imu)
    ldim_dump.py inspect / CSV dump
    ldim_to_floorplan.py uses GYRO_SIGN=-1 for this rig's +Z-up IMU frame
    (the Pi mount was inverted; +1 there produced a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
    [touch_test.ino]
2026-06-01 docs: document touch UI, IMU, recording + host toolchain
    Update the README for the new firmware/tooling: touch controls (TRACK /
    AREA / IMU / REC), the BMI160 IMU and its wiring, on-device .ldim
    recording, and the tools/ pipeline (pull-recordings / floorplan / viz /
    mcap / view). Also correct the SoftAP / mDNS names to match the firmware
    (lidar-setup / lidar.local, not battle).
2026-06-01 docs: add sample floorplan image to README
    Floorplan rendered from a ~50 s handheld walk (scan_005) via
    `make floorplan`. Force-added since *_floorplan.png is gitignored.
2026-06-24 Improve floorplan IMU pipeline; tidy 3D tilt and GUI
    Floorplan (ldim_to_floorplan.py):
    - Kalman tilt filter (build_orientation_kf) as the default, fusing gyro
    (predict) with accelerometer (gravity correction), measurement noise
    scaled by |a|-1g so walking motion is down-weighted. Tuned to
    gate=0.03, q_ang=20 (loop-closure translation 0.138 -> 0.032 m on
    scan_006). --no-kf falls back to the complementary filter.
    - Rewrote operator strip: per-revolution persistence detection, full
    blank on the occluded body core, conservative band on dilated edges,
    plus a 0.25 m global near-floor; clears the start-pose shadow without
    eating walls.
    - Recover faint walls: hysteresis threshold (keep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
2026-07-02 Improve floorplan SLAM: point-to-line ICP, translation deskew, global refinement
    scan_006 walls 2.46->1.83 cm, wall cells -19%; adds tools/floorplan_bench.py
    for the map-quality metrics. All stages default on (--p2p / --no-deskew-xy /
    --no-refine revert).
2026-07-05 Add position-path PNG: --path render mode, make target, GUI button
    Renders the SLAM trajectory (light-to-dark blue by time, labeled
    start/end, time colorbar) over a faint point map, using the same
    mirror/straighten transform as the floorplan so the two line up.
2026-07-05 README: document the desktop GUI with screenshots + path sample
